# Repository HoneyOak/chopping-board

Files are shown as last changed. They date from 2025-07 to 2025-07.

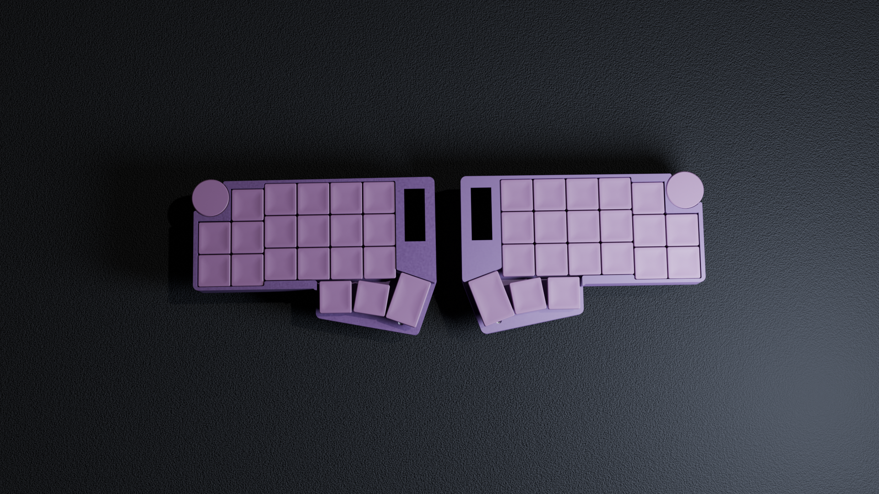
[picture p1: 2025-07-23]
images/render-1.png

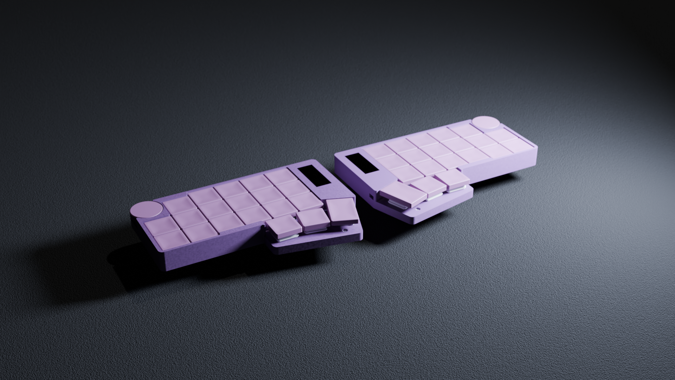
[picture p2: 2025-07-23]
images/render-2.png

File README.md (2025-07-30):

# Chopping Board

blender2

A minimal 40 key low-profile split ortholinear keyboard. Designed with simplicity and versatility in mind.

Split keyboards are a revelation in terms of ergonomics. I wanted to build a split ortholinear keyboard that looks clean and is designed with intention. I took aspects from the Corne and Totem to acheive this minimal yet complete keyboard.

## Features
- Hotswappable
- Low Profile
- 128x32 OLED on each side
- Low profile knobs on each side
- 40 keys
- _Flippable_ PCB _oO_
- Corne style thumb cluster
- Choc v1 switches
- ZMK Firmware
- Replicable, 3D printable and fully open source
# Images
blender

## Schematic


## PCB




## Onshape
[Link to onshape document](https://cad.onshape.com/documents/f44f4f4ef5a39d6812b8dac0/w/095a0f8541f1a3b1fc930aaf/e/dd0d0b078a574b8c9309113b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)


# Credits
- Erogogen - https://github.com/ergogen/ergogen
- Ceolide's Ergogen Footprints - https://github.com/ceoloide/ergogen-footprints

# BOM
#### Total Price: $105.18
| name | quantity | price US$ | total (US$) | link | notes |
| --- | --- | --- | --- | --- | --- |
| power switch | 1 | 1.511627907 | 1.51 | [https://robu.in/product/pcm12smtr-ck-standing-paste-single-pole-double-throw-spdt-6v-smd-slide-switches-rohs/](https://robu.in/product/pcm12smtr-ck-standing-paste-single-pole-double-throw-spdt-6v-smd-slide-switches-rohs/) | |
| reset button | 1 | 1.736046512 | 1.74 | [https://in.element14.com/c-k-components/pts636-sl43-smtr-lfs/tactile-switch-0-05a-12vdc-130gf/dp/3780603](https://in.element14.com/c-k-components/pts636-sl43-smtr-lfs/tactile-switch-0-05a-12vdc-130gf/dp/3780603) | 10 minimum order |
| ec12 rotary encoder | 2 | 0.6976744186  | 1.40 | [https://rees52.com/products/rotary-encoder-ec12-audio-digital-potentiometer-5mm-handle-rs1258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](https://rees52.com/products/rotary-encoder-ec12-audio-digital-potentiometer-5mm-handle-rs1258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) | |
| m2 small screws | 4 | 0.02744186047 | 0.11 | [https://onlyscrews.in/products/m2-x-6mm-phillips-pan-head-ss-304-screw?_pos=2&_sid=e9e4a7851&_ss=r](https://onlyscrews.in/products/m2-x-6mm-phillips-pan-head-ss-304-screw?_pos=2&_sid=e9e4a7851&_ss=r) | Pack of 25 |
| m2 small heatset inserts | 4 | 0.02197674419 | 0.09 | [https://onlyscrews.in/products/m2-x-3mm-brass-threaded-inserts](https://onlyscrews.in/products/m2-x-3mm-brass-threaded-inserts) | |
| supermini nrf52840 | 1 | 7.662790698 | 7.66 | [https://probots.co.in/pro-micro-nrf52840-development-board-compatible-with-nice-nano-v2-0.html](https://probots.co.in/pro-micro-nrf52840-development-board-compatible-with-nice-nano-v2-0.html) | |
| Kailh Choc Hotswap Sockets | 4 | 1.686046512 | 6.74 | [https://neomacro.in/products/kailh-choc-pg1350-hot-swap-sockets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](https://neomacro.in/products/kailh-choc-pg1350-hot-swap-sockets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) | Packs of 10 |
| Battery | 1 | 1.337209302 | 1.34 | [https://www.electropi.in/3.7v-90mah-lipo-battery-model-351028-india](https://www.electropi.in/3.7v-90mah-lipo-battery-model-351028-india) | |
| SMD Diodes | 40 | 0.06488372093 | 2.60 | [https://evelta.com/1n4148w-7-f-switching-diode/](https://evelta.com/1n4148w-7-f-switching-diode/) | |
| Switches | 4 | 8.139534884 | 32.56 | [https://typeractive.xyz/products/choc-switches?variant=46024772387047](https://typeractive.xyz/products/choc-switches?variant=46024772387047) | Packs of 10 |
| Keycaps 1 | 4 | 4.651162791 | 18.60 | [https://typeractive.xyz/products/mbk-keycaps?variant=48512019497191](https://typeractive.xyz/products/mbk-keycaps?variant=48512019497191) | Packs of 10 |
| Keycaps 1.5 | 1 | 2.325581395 | 2.33 | [https://typeractive.xyz/products/mbk-keycaps?variant=48512020283623](https://typeractive.xyz/products/mbk-keycaps?variant=48512020283623) | Packs of 2 |
| Keycaps 1 homing | 1 | 1.162790698 | 1.16 | [https://typeractive.xyz/products/mbk-keycaps?variant=48512019759335](https://typeractive.xyz/products/mbk-keycaps?variant=48512019759335) | Packs of 2 |
| 128x32 OLED | 2 | 1.476744186 | 2.953488372 | [https://www.electropi.in/0.91-inch-i2c-iic-128x32-oled-display-module?gPromoCode=EPJul2ndSale](https://www.electropi.in/0.91-inch-i2c-iic-128x32-oled-display-module?gPromoCode=EPJul2ndSale) | |
| PCB Fab | 1 | 24.39534884 | 24.40 | [https://www.lioncircuits.com](https://www.lioncircuits.com) | 5 minimum order  |
| Total | | | 105.18 | | |

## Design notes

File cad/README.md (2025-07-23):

STEP file too big so had to compress as zip.
Onshape Link:
https://cad.onshape.com/documents/f44f4f4ef5a39d6812b8dac0/w/095a0f8541f1a3b1fc930aaf/e/dd0d0b078a574b8c9309113b

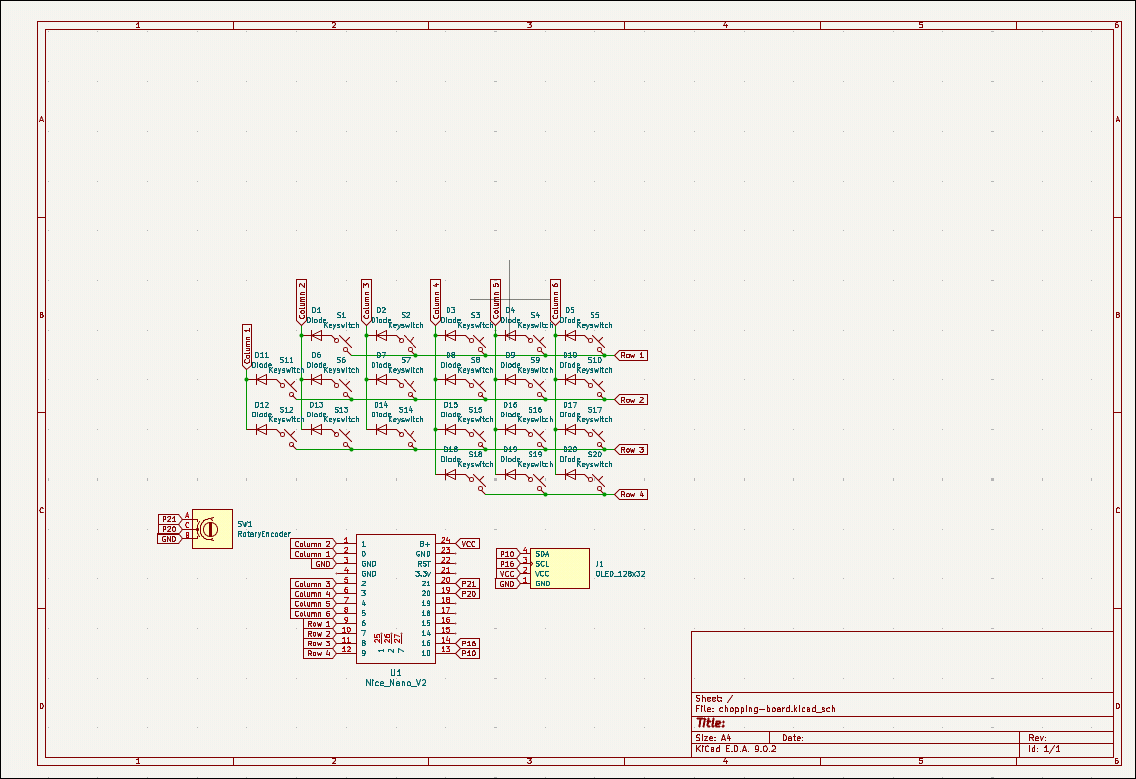
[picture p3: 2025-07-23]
images/schematic.png

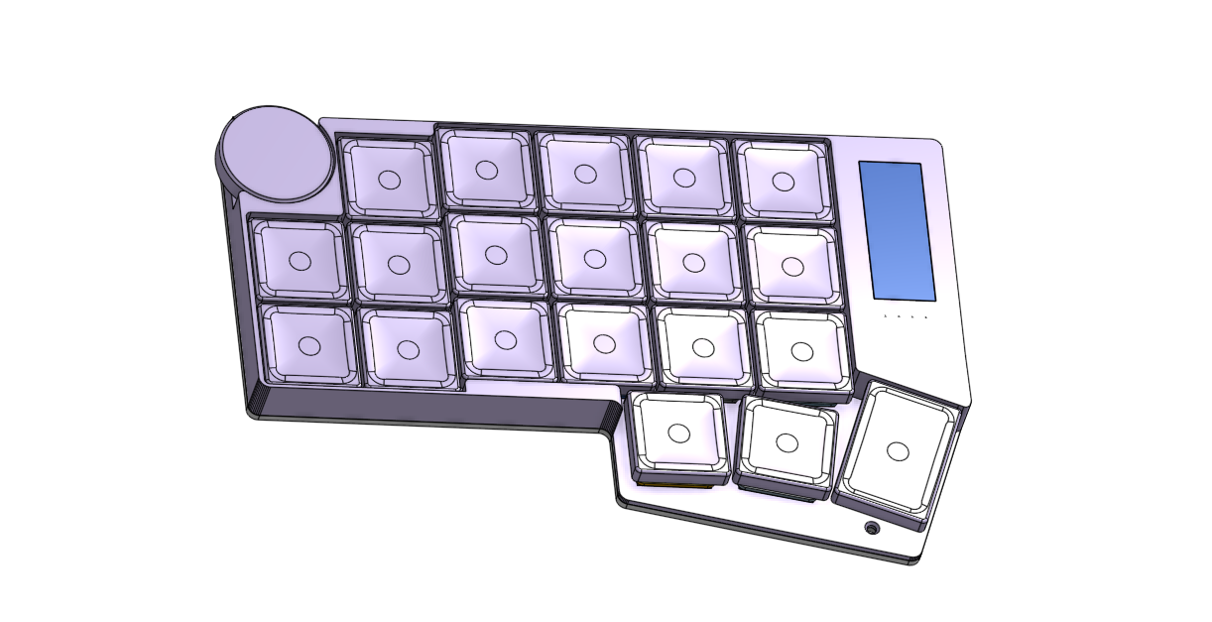
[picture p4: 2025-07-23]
images/onshape.png

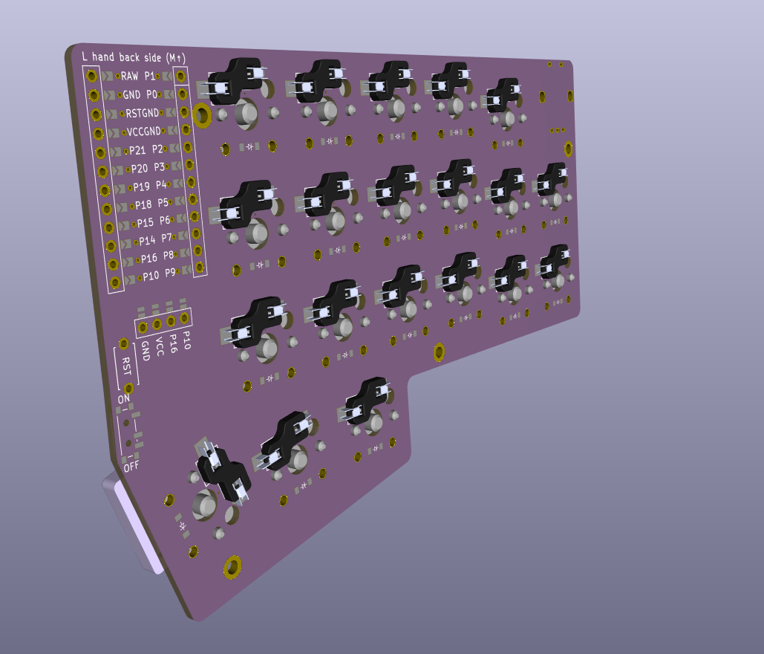
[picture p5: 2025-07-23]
images/pcb-3d-1.png

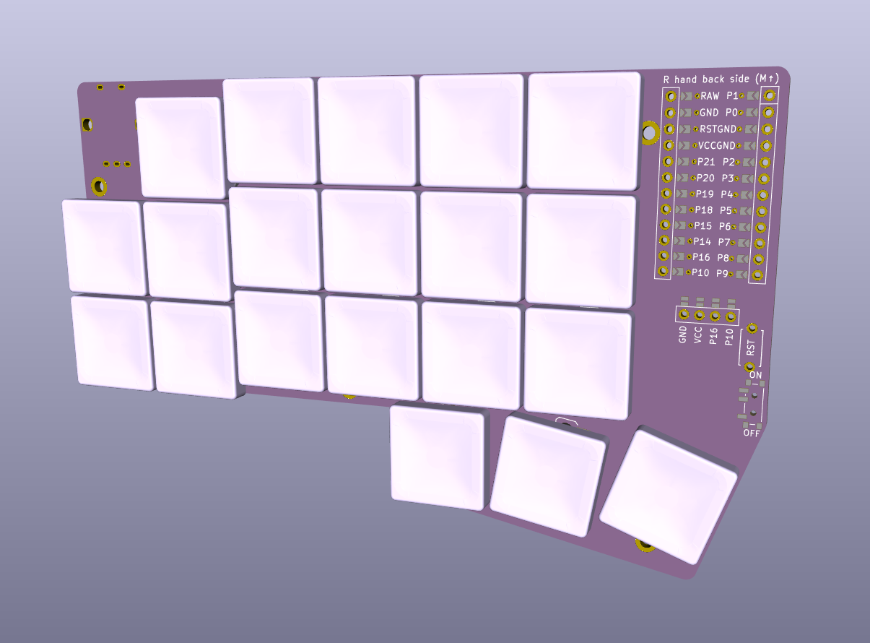
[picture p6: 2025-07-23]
images/pcb-3d-2.png

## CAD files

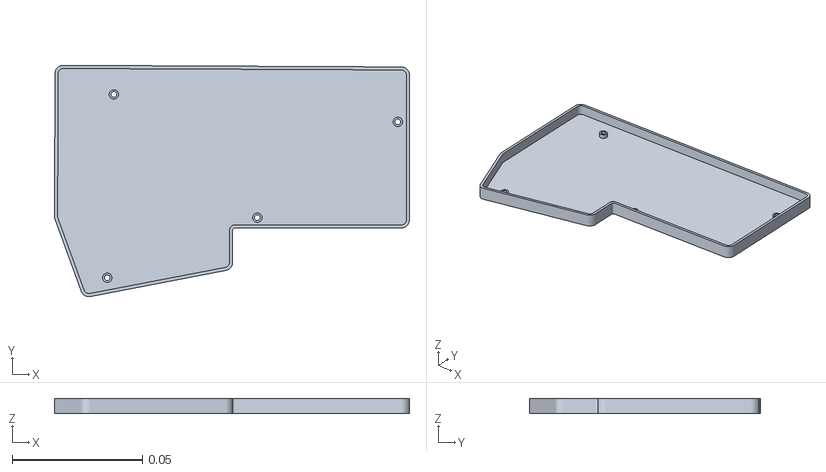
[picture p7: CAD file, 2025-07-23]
production/case - bottom-case-right.stl
0.137 x 0.089 x 0.00579

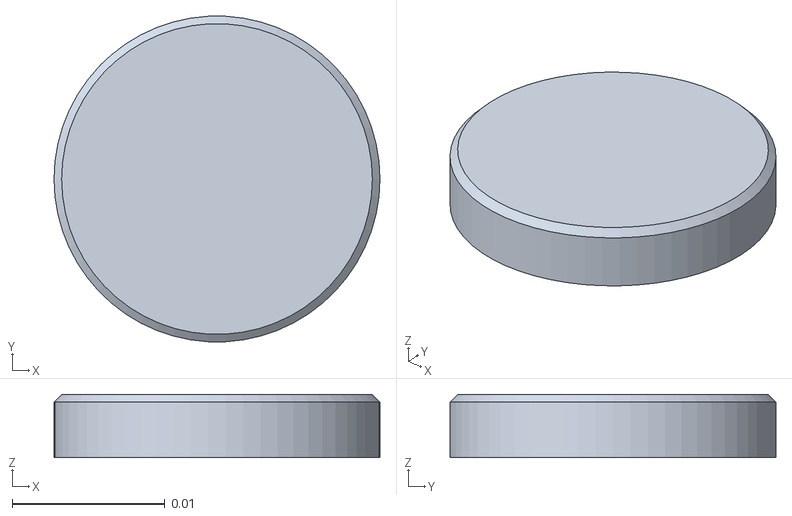
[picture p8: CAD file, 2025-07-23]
production/case - knob.stl
0.0213 x 0.0213 x 0.00413

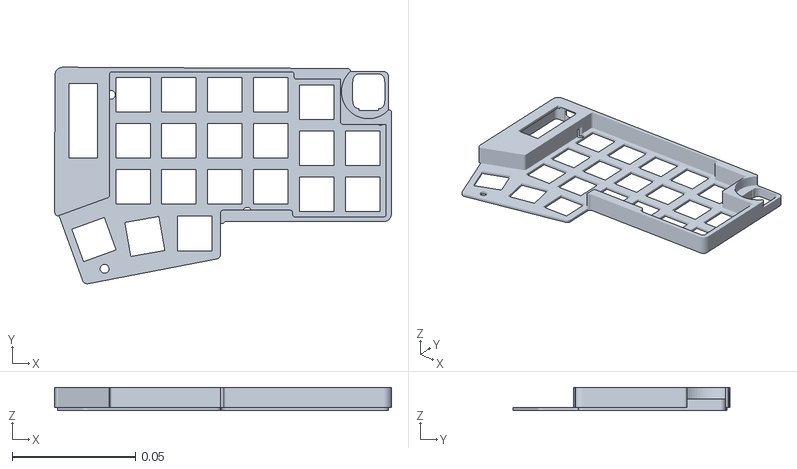
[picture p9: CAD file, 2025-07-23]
production/case - top-case-right.stl
0.137 x 0.0878 x 0.00945

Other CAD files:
production/case - bottom-case.stl
production/case - knob-right.stl
production/case - top-case.stl
blender/assets/materials/black-matte-plas_eb3e7111-7e51-4323-a675-54e68917ef0c/black-matte-plastic-low-damaged_72571f2a-99d8-4621-a9b1-74b2bd40d508.blend
blender/assets/materials/matte-black-leat_b0d1845e-90a8-4ecc-8731-020a59176e04/matte-black-leather_2K_4da69b24-6c78-4045-abc5-27fba0a4dea0.blend
blender/assets/materials/plain-purple-fla_03af8c7e-b747-4bf0-8d49-94a0c281a485/plain-purple-flat_2K_456321e2-213b-41c5-9664-62b127ec30c6.blend
blender/assets/materials/plain-purple-fla_1fc4ea51-0eba-4c20-8d0f-1850c3657551/plain-purple-flat_2K_65b56266-50dd-4a5d-815e-67eeebd7a022.blend
blender/assets/materials/plain-purple-tex_f1485d6e-f5f4-410c-bac8-df98b3443202/plain-purple-texture_2K_d3b9ebbd-188c-42e7-a361-8166a4e7eda5.blend
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

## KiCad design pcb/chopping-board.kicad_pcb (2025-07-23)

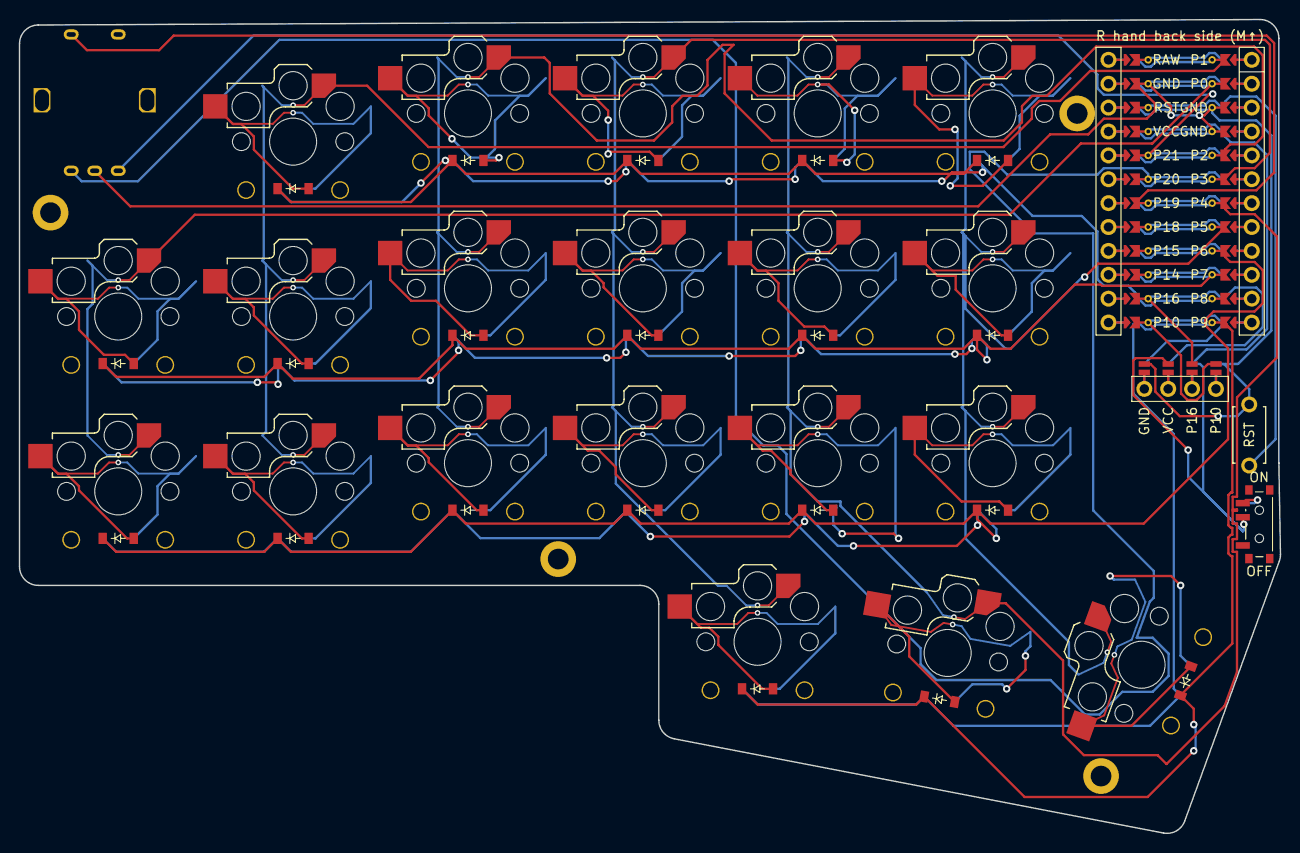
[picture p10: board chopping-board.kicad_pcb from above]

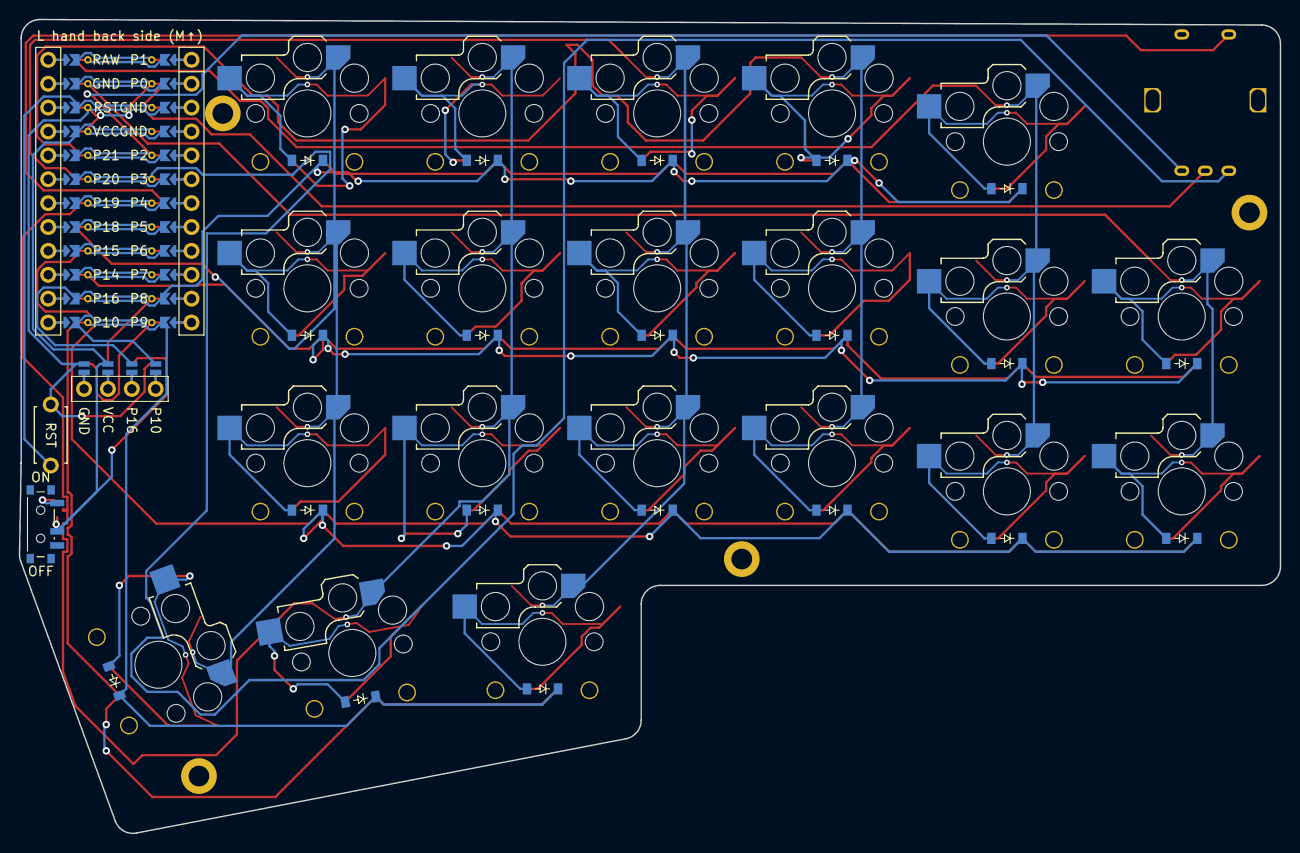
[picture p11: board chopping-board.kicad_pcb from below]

Board: 2 copper layers, 134.1 x 86.6 mm, 49 parts (20 on the bottom side), 43 nets.

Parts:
D1, D2, D3, D4, D5, D6, D7, D8, D9, D10, D11, D12, D13, D14, D15, D16, D17, D18, D19, D20: diode_tht_sod123
DISP1: display_ssd1306
H1, H2, H3, H4: mounting_hole_plated
MCU1: mcu_nice_nano
PWR1: power_switch_smd_side
RE1: rotary_encoder_ec11_ec12
RST1: reset_switch_tht_top
S1, S2, S3, S4, S5, S6, S7, S8, S9, S10, S11, S12, S13, S14, S15, S16, S17, S18, S19, S20: switch_choc_v1_v2

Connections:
BAT+: PWR1.1, PWR1.3
DISP1_1: DISP1.1, DISP1.10, DISP1.23
DISP1_2: DISP1.2, DISP1.11, DISP1.22
DISP1_3: DISP1.3, DISP1.12, DISP1.21
DISP1_4: DISP1.4, DISP1.13, DISP1.20
GND: DISP1.14, DISP1.24, MCU1.103, MCU1.104, MCU1.123, RE1.B, RST1.2
P0: MCU1.102, S1.1, S2.1
P1: MCU1.101, S3.1, S4.1, S5.1
P2: MCU1.105, S6.1, S7.1, S8.1
P3: MCU1.106, S9.1, S10.1, S11.1, S18.1
P4: MCU1.107, S12.1, S13.1, S14.1, S19.1
P5: MCU1.108, S15.1, S16.1, S17.1, S20.1
P6: D1.1, D3.1, D6.1, D9.1, D12.1, D15.1, MCU1.109
P7: D2.1, D4.1, D7.1, D10.1, D13.1, D16.1, MCU1.110
P8: D5.1, D8.1, D11.1, D14.1, D17.1, MCU1.111
P9: D18.1, D19.1, D20.1, MCU1.112
P10: DISP1.17, DISP1.27, MCU1.113
P16: DISP1.16, DISP1.26, MCU1.114
P19: MCU1.118, RE1.S1
P20: MCU1.119, RE1.C
P21: MCU1.120, RE1.A
RST: MCU1.122, RST1.1
VCC: DISP1.15, DISP1.25, MCU1.121, PWR1.2
index_bottom: D12.2, S12.2
index_home: D13.2, S13.2
index_top: D14.2, S14.2
inner_bottom: D15.2, S15.2
inner_extra: D18.2, S18.2
inner_home: D16.2, S16.2
inner_top: D17.2, S17.2
middle_bottom: D9.2, S9.2
middle_extra: D19.2, S19.2
middle_home: D10.2, S10.2
middle_top: D11.2, S11.2
outer_bottom: D1.2, S1.2
outer_extra: D20.2, S20.2
outer_home: D2.2, S2.2
pinky_bottom: D3.2, S3.2
pinky_home: D4.2, S4.2
pinky_top: D5.2, S5.2
ring_bottom: D6.2, S6.2
ring_home: D7.2, S7.2
ring_top: D8.2, S8.2

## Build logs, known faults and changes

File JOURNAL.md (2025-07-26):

---
title: "Chopping Board"
author: "HoneyOak"
description: "A 40 key split olkb focused on simplicity and versatility."
created_at: "2025-07-10"
---

# Road to Chopping Board
#### Total hours so far: 25.5
## 2025-07-11 Research (1.5 hours)
Exploring current keyboard options and noting what I want. I like the minimalism of the Totem and the layout of the Corne. A low profile keyboard is a must. Aesthetics are just as important as ergonomics.
Perhaps, then, a slightly staggered layout with a simple thumb cluster is what I should be going for.

## 2025-07-12 Schematic (2 hours)
Done with a quick schematic! Decided the components I need: nice nano v2 MCU, hotswappable choc switches, diodes, knob, and an oled. As a bonus, the schematic for the two halves are the exact same. I plan to make a flippable PCB so I don't need to order 5 of each half. 



## 2025-07-14 PCB design (8 hours)
After hours of fiddling with grids and splayed layouts in KiCAD, and the flippabality headache at the back of my mind, I surrender. I surrender to ergogen my beloved. Not sure if this is against the rules, but I just need the PCB Layout from on here. I have the schematic already, just need the components placed in the right layout (and the pcb to be flippable). Anyway, after a long side quest here's what I came up with:




So beautiful. Headache over.

## 2025-07-16 CAD design (1 hour)

Just importing the files of the PCB and the components into an OnShape assembly. Here's what it looks so far:



The actual case is yet to be made!

## 2025-07-16 Back to KiCAD for a bit (1.5 hours)
Fixed up the layout, added 3d models. Routing is still TBD, but the rest is laid out!





## 2025-07-21 CAD (5.5 hours)
Almost done with cad! Really like how it's coming along. Lots of progress on the BOM too. 



## 2025-07-22 CAD (3.5 hours)
CAD finished! Did bottom plate + screw holes. Took some time to render it out in blender.

blender
blender2

## 2025-07-23 PCB (2.5 hours)
PCB trace routing done! :D


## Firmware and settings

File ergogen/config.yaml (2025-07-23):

meta:
  engine: 4.1.0
units:
  # Proxy Spacing Variables
  kx: cx
  ky: cy
  # Padding Variables
  px: kx + 3
  py: ky + 3
points:
  zones:
    matrix:
      anchor:
        shift: [50, -150]
      key:
        padding: 1kx  + 0.6
        spread: 1kx + 0.6
      columns:
        outer:
          rows.top.skip: true
          key.column_net: P0
        pinky:
          key.column_net: P1
        ring:
          key:
            column_net: P2
            stagger: 3
        middle:
          key.column_net: P3
        index:
          key.column_net: P4
        inner:
          key.column_net: P5
      rows:
        bottom:
          row_net: P6
        home:
          row_net: P7
        top:
          row_net: P8
    thumb:
      key:
        padding: 1ky
        spread: 1kx
      anchor:
        ref: matrix_inner_bottom
        shift: [-kx, -ky - 2]
      columns:
        inner:
          key:
            shift : [-7, 0]
            column_net: P3
        middle:
          key:
            shift: [-4.5, -2]
            splay: -10
            column_net: P4
        outer:
          key:
            width: 1.5kx
            splay: 80
            shift: [0, 2]
            column_net: P5

      rows:
        extra:
          row_net: P9

outlines:
  raw:
    - what: rectangle
      where: true
      size: [px, py]
      fillet: 2
  cutout:
    - what: rectangle
      where: true
      size: [14,14]
  board:
    - what: polygon
      operation: stack
      points:
        - ref: thumb_outer_extra
          shift: [0.75px,-0.5py]
        # - ref: thumb_outer_extra
        #   shift: [0.75px,0.5py]
        - ref: matrix_inner_bottom
          shift: [0.5px + 0.95px,0]
        - ref: matrix_inner_top
          shift: [0.5px + 0.95px,0.5py]
        - ref: matrix_outer_home
          shift: [-0.5px,kx + 0.5py + 3]
        - ref: matrix_outer_bottom
          shift: [-0.5px,-0.5py]
        - ref: thumb_inner_extra
          shift: [-0.5px,0.5py - 4]
        - ref: thumb_inner_extra
          shift: [-0.5px,-0.5py]  
        - ref: thumb_outer_extra
          shift: [-0.75px,-0.5py]
      fillet: 2
  combo:
    - name: board
    - operation: subtract
      name: cutout


pcbs:
  left:
    template: kicad8
    outlines:
      main:
        outline: board
    footprints:
      keyswitches:
        where: true
        what: switch_choc_v1_v2
        params:
          hotswap: true
          reversible: true
          hotswap_3dmodel_filename: '/home/soham/Downloads/chopping-board-steps/PG1350-socket.STEP'
          hotswap_3dmodel_xyz_rotation: [90,0,0]
          hotswap_3dmodel_xyz_offset: [10, -6, 0]
          switch_3dmodel_filename: '/home/soham/Downloads/chopping-board-steps/switch.STEP'
          switch_3dmodel_xyz_rotation: [90, 0, 90]
          switch_3dmodel_xyz_offset: [0, 0, -4]
          keycap_3dmodel_filename: '/home/soham/Downloads/chopping-board-steps/purple-cap.step'
          keycap_3dmodel_xyz_offset: [0, 0, -7]
          from: "{{column_net}}"
          to: "{{colrow}}"
      diode:
        what: diode_tht_sod123
        where: true
        params:
          from: "{{colrow}}"
          to: "{{row_net}}"
          reversible: true
        adjust:
          shift: [0, -5]
      mcu:
        what: mcu_nice_nano
        where:
          ref: matrix_inner_top
          shift: [0.95px, -7]
          rotate: 0
        params:
          reversible: true
      knob:
        what: rotary_encoder
        where:
          ref: matrix_outer_home
          shift: [-2.5, 1px + 2]
          rotate: 0
        params:
          A: P21
          B: GND
          C: P20
          S1: P19
          reversible: true
      reset:
        what: reset_switch_tht_top
        params:
          from: GND
          to: RST
          reversible: true
        where:
          ref: matrix_inner_bottom
          shift: [1.3px, 3]
          rotate: -90

      oled:
        what: display_ssd1306
        params:
          reversible: true
          SDA: P10
          SCL: P16
        where:
          ref: matrix_inner_home 
          shift: [0.95px, 6]
      power_switch:
        what: power_switch
        where:
          ref: matrix_inner_bottom
          shift: [1.35px, -6.5]
          rotate: 0
        params:
          from: BAT+
          to: VCC
          reversible: true
      holeTopLeft:
        what: mounting_hole_plated
        where:
          - ref: matrix_outer_home
            shift: [-0.4kx, 0.65ky]
      holeBottomLeft:
        what: mounting_hole_plated
        where:
          - ref: matrix_middle_bottom
            shift: [-0.5kx, -0.6ky]
      holeTopRight:
        what: mounting_hole_plated
        where:
          - ref: matrix_inner_top
            shift: [0.5kx, 0]
      holeBottomRight:
        what: mounting_hole_plated
        where:
          - ref: thumb_outer_extra
            shift: [-0.7kx, 0]



cases:
  plate:
    - name: combo
      extrude: 1.2

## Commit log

2025-07-25 Update BOM
2025-07-30 add blend
    [chopping-board.blend]
2025-07-30 add blender assets
    [black-matte-plastic-low-damaged_72571f2a-99d8-4621-a9b1-74b2bd40d508.blend, matte-black-leather_2K_4da69b24-6c78-4045-abc5-27fba0a4dea0.blend, plain-purple-fla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]
